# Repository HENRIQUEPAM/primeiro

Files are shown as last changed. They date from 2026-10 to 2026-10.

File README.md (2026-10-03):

# Suporte de mesa (moldura) para celular — impressão 3D

Dimensionado para o **Xiaomi Redmi 13C** (168 × 78 × 8,09 mm, 192 g).
Peça única, sem encaixes e sem parafusos. Segura o celular em pé na mesa,
em **retrato ou paisagem**, e permite **carregar o aparelho apoiado**.

**Arquivo para imprimir:** [`stl/suporte-celular-moldura.stl`](stl/suporte-celular-moldura.stl)

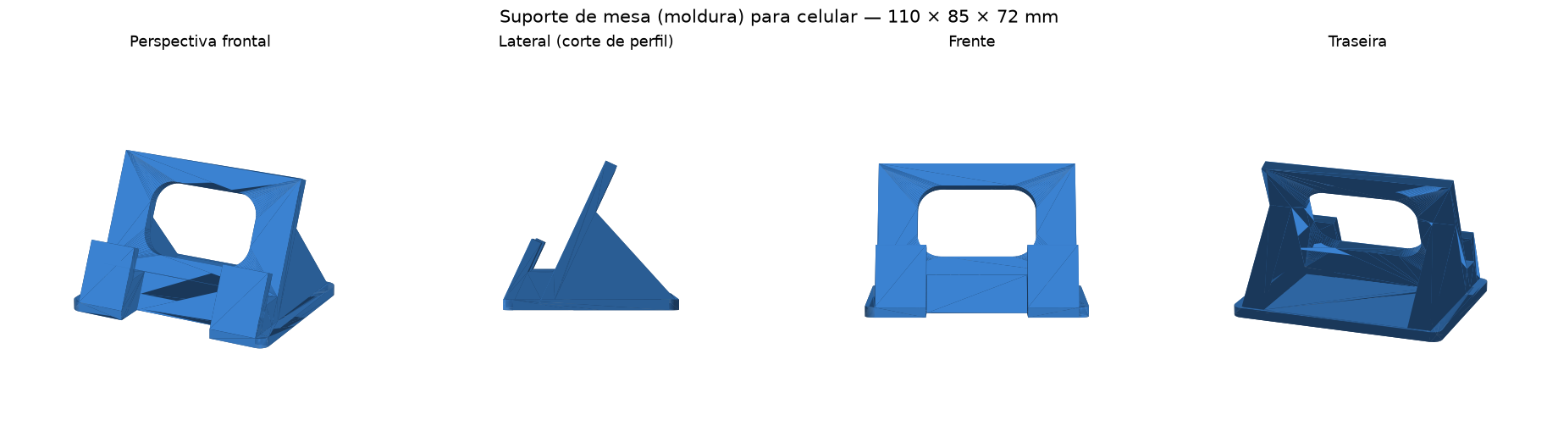
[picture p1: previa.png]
prévia


## Medidas

| | |
|---|---|
| Dimensões externas | 110 × 85 × 72 mm |
| Inclinação do aparelho | 25° em relação à vertical |
| Canal de apoio | 11,5 mm (aparelho de 8,09 mm + 3,4 mm de folga para capa fina) |
| Altura do piso acima da mesa | 18 mm |
| Aba de retenção acima do piso | 14 mm |
| Vão central para o cabo | 50 mm de largura × 18 mm de altura, aberto até a frente |
| Volume | 119 cm³ (≈ 56 g em PLA com 20% de preenchimento) |

O aparelho encosta na moldura e a aba frontal impede que escorregue. A
folga de 3,4 mm acomoda uma capa fina; com capa grossa (tipo anti-impacto)
é preciso aumentar `CANAL` no script e regerar.

O vão central de 50 mm deixa livres o conector USB-C **e** o alto-falante
inferior — a aresta de baixo do aparelho apoia nos 14 mm de piso de cada
lado do vão.

Em paisagem o aparelho apoia sobre os 100 mm da aba e sobrepõe as laterais —
é o uso normal e continua estável (centro de massa do conjunto a 41 mm, contra
85 mm de base; em retrato, 55 mm).

## Configuração de impressão

- **Posição:** como está no STL, apoiado na base. **Sem suportes.**
- **Altura de camada:** 0,2 mm
- **Paredes:** 3 perímetros
- **Preenchimento:** 15–20% (giroide ou grade)
- **Material:** PLA ou PETG. Evite PLA se o suporte ficar em carro ou ao sol.
- **Brim:** não é necessário; a base tem 110 × 85 mm de contato.
- **Tempo estimado:** 4 a 6 h, dependendo da impressora.

O único trecho em ponte é o topo da janela da moldura (36 mm de vão), que
qualquer impressora calibrada faz sem problema.

### Acabamento recomendado

Cole quatro pés de feltro ou um retângulo de EVA sob a base — além de não
riscar a mesa, aumenta o atrito e impede que o conjunto deslize quando você
toca na tela.

## Como foi gerado

O STL foi construído por `gerar_suporte.py` (Python + trimesh + manifold3d).
Você não precisa dele para imprimir — está no repositório apenas como
registro da geometria, caso um dia queira alterar alguma medida:

```bash
pip install trimesh manifold3d shapely mapbox_earcut numpy scipy
python3 gerar_suporte.py
```

Os parâmetros ficam todos no bloco do topo do arquivo (inclinação, folga do
canal, largura, espessuras, tamanho da janela).

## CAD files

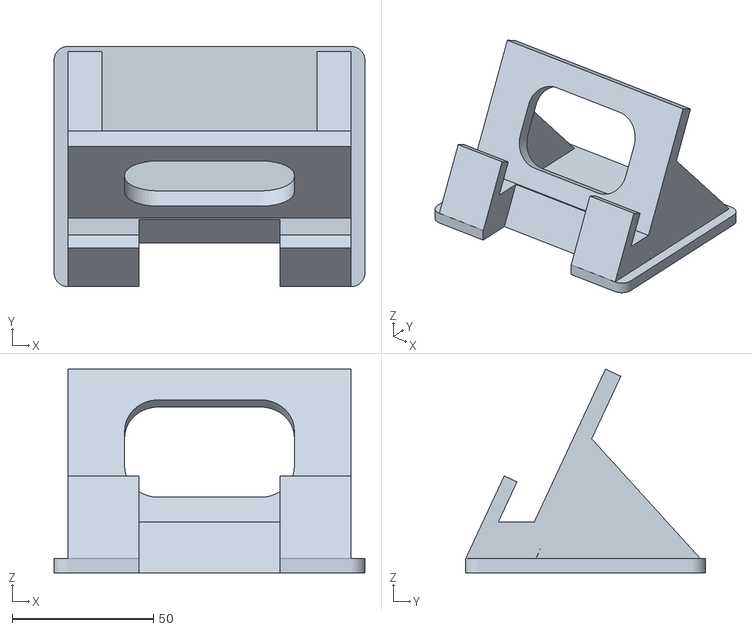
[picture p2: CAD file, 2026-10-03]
stl/suporte-celular-moldura.stl
110.0 x 85.0 x 72.1

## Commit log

2026-09-28 Adiciona suporte de mesa (moldura) para celular em STL
    Peça única para impressão 3D, sem suportes, que segura o celular em
    retrato ou paisagem e permite carregá-lo apoiado.
    - stl/suporte-celular-moldura.stl: arquivo pronto para fatiar
    (110 x 85 x 72 mm, malha estanque, corpo único)
    - gerar_suporte.py: geração paramétrica da geometria (trimesh + manifold3d)
    - previa.png: vistas do modelo
    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
    [suporte-celular-moldura.stl]
2026-10-03 Ajusta o suporte as medidas do Redmi 13C
    Com o modelo confirmado (168 x 78 x 8,09 mm, 192 g), o encaixe deixa de
    ser genérico e passa a ser dimensionado:
    - canal de 14 para 11,5 mm (8,09 mm do aparelho + 3,4 mm para capa fina),
    reduzindo a folga em que o aparelho balançava
    - moldura avançada 2,7 mm (Y0 de 21 para 18,3 mm) para a aba voltar a
    ficar rente à frente da base com o canal mais estreito
    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
    [suporte-celular-moldura.stl]
